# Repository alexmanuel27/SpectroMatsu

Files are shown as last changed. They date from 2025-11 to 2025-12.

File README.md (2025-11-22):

# SpectroMatsu

A lightweight, portable, open-source spectrophotometer designed for in-situ water quality and other compound analysis. Built with the Hamamatsu C12880MA miniature spectrometer sensor and the 3-channel ultraviolet AS7331 light sensor.

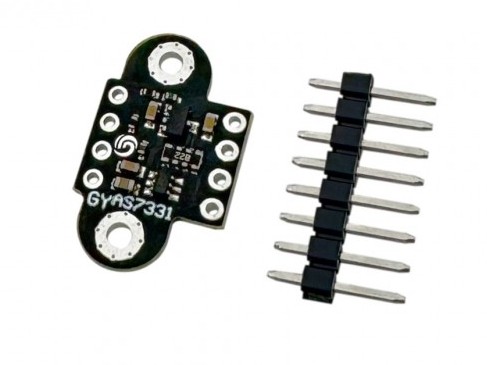
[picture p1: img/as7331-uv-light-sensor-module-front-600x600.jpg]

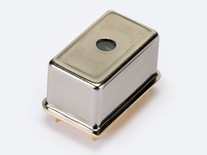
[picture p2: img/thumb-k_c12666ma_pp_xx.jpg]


## Table of Contents

- [Features](#features)
- [Hardware](#hardware)
  - [Sensor](#sensor)
  - [Microcontroller & Display](#microcontroller--display)
  - [Hardware Design (PCB)](#hardware-design-pcb)
- [Software](#software)
- [Installation](#installation)
- [Usage](#usage)
- [License](#license)

## Features

*   **Portable & Low-Cost:** Designed for field use with a focus on affordability.
*   **Open Source:** Hardware schematics and software are freely available.
*   **Real-Time Data:** Captures and displays absorbance spectra.
*   **Local Data Storage:** Saves measurement samples to an external EEPROM.
*   **WiFi Connectivity:** Enables a local web interface for data access and control.
*   **Intuitive Touch Interface:** Easy-to-use graphical menu system on a 1.9" color display.
*   **Sample Management:** Functions to take, save, list, and download sample data (individually or in bulk) via the local web interface.

## Hardware

### Sensor

*   **Model:** 
    *   Hamamatsu C12666MA
    *   AS7331
*   **Type:** Combined miniature linear image sensor for spectral analysis and optical filters with the AS7331 sensor to achieve a broader spectral range.
*   **Spectral Range:** A combination of visible and ultraviolet light, suitable for detecting various water quality indicators through absorbance measurements.
*   **Integration:** Interfaces directly with the custom-designed PCB for signal conditioning and data acquisition.

### Microcontroller & Display

*   **Microcontroller:** ESP32-S3 (specifically, the LilyGo T-Display-S3 module).
*   **Features:** WiFi capability, sufficient processing power for basic spectroscopic calculations.
*   **Display:** 1.9" 320x170 pixel color TFT LCD with capacitive touch panel.
*   **Purpose:** Provides the user interface for control, data visualization (spectra), and menu navigation.

### Hardware Design (PCB)

*   **Status:** Custom-designed PCB specifically for integrating the Hamamatsu C12666MA sensor with the LilyGo T-Display-S3.

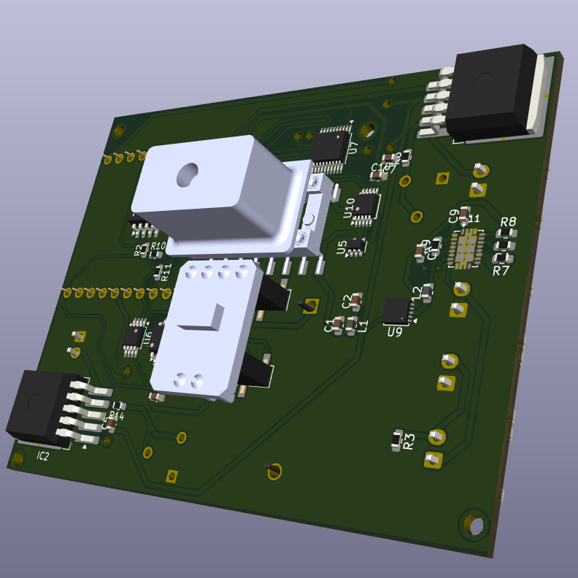
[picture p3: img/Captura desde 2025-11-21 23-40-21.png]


*   **Functionality:**
    *   Includes the necessary components for sensor biasing, timing, and signal conditioning (e.g., amplification, filtering).
    *   Interfaces with the LilyGo T-Display-S3's GPIO pins for data acquisition and control.
    *   Provides stable mechanical mounting for the sensor relative to the optical path.

## Software

*   **Platform:** PlatformIO.
*   **Core Functionality:**
    *   Processes raw sensor data to generate absorbance spectra.
    *   Provides a graphical user interface (GUI) on the TFT display using a state machine architecture.
    *   Handles touch input for navigation and control.
    *   Stores measurement data (samples) on an external EEPROM of the ESP32.
    *   Manages WiFi access point (AP) mode.
    *   Runs a local web server providing a web interface for sample listing and downloading (CSV format).
    *   Implements a simple menu system accessible via the touchscreen.

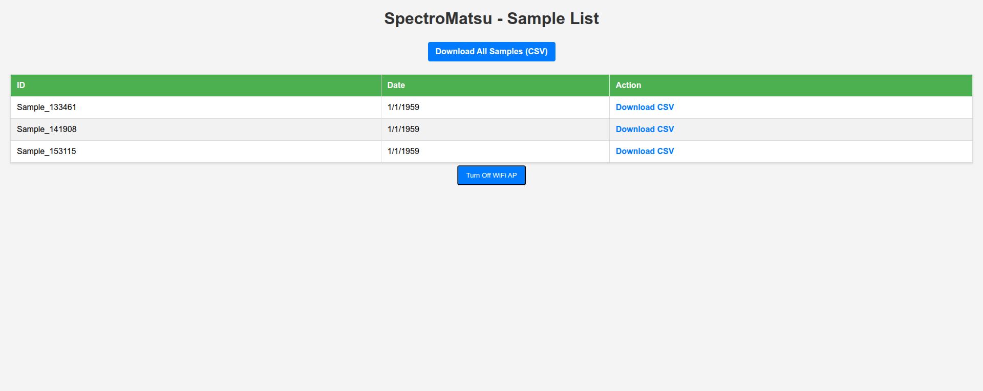
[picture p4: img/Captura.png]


### Key Functionalities

#### Sample Taking:

*   Navigate to the main screen.
*   Press the "REFER" button.
    *   The system saves the blank/reference value for later absorbance calculation.
*   Press the "SAMPLE" button.
    *   The system enters an acquisition and absorbance calculation phase.
*   After acquisition, the resulting spectrum is displayed.
*   Press the "SAVE" button to store the spectrum in the EEPROM with a generated name.

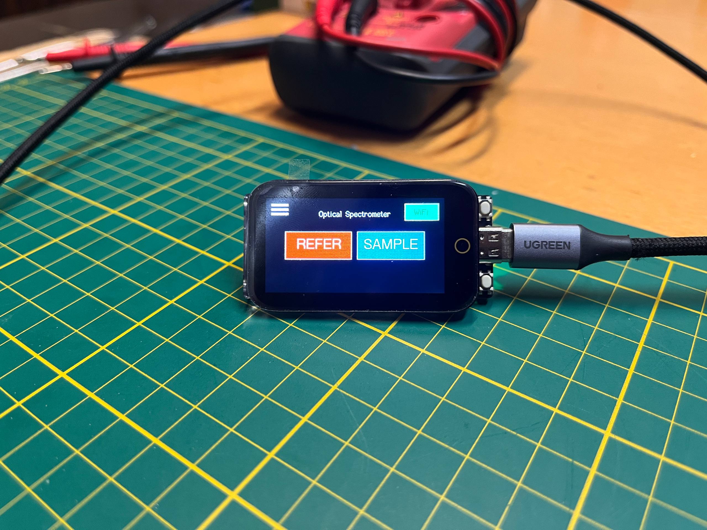
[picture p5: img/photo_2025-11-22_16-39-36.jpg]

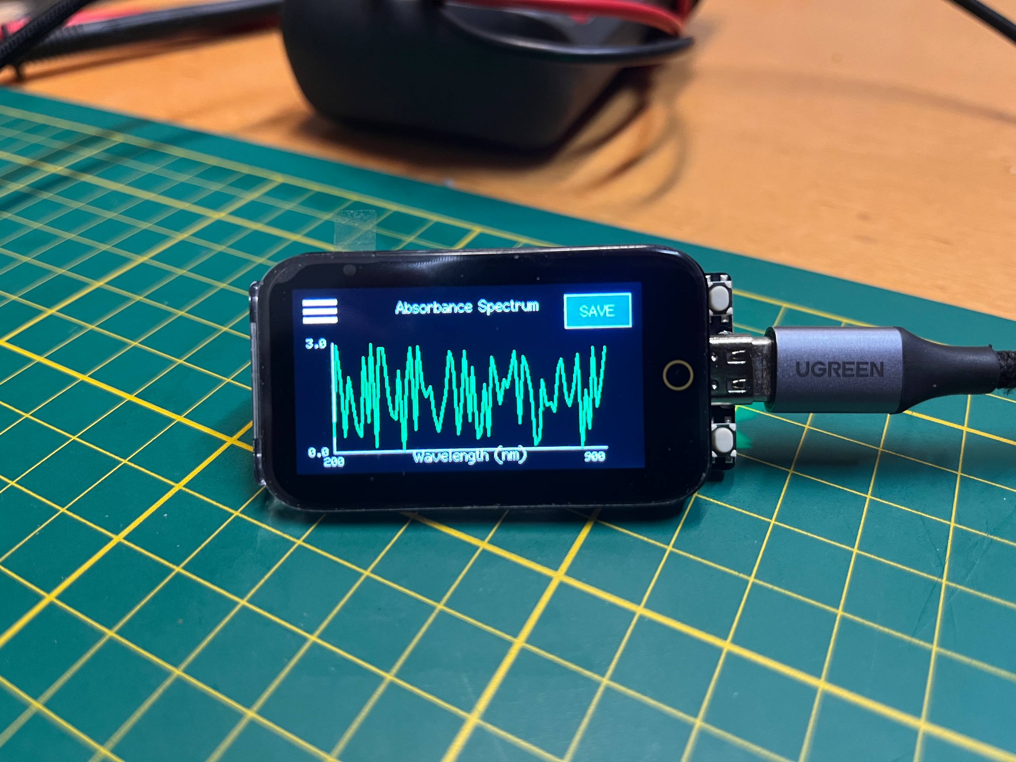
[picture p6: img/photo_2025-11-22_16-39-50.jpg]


#### Sample Listing:

*   Access the main menu (hamburger icon).
*   Select "SAMPLES".
*   A list of saved sample names and dates (default date shown) is displayed on the screen.

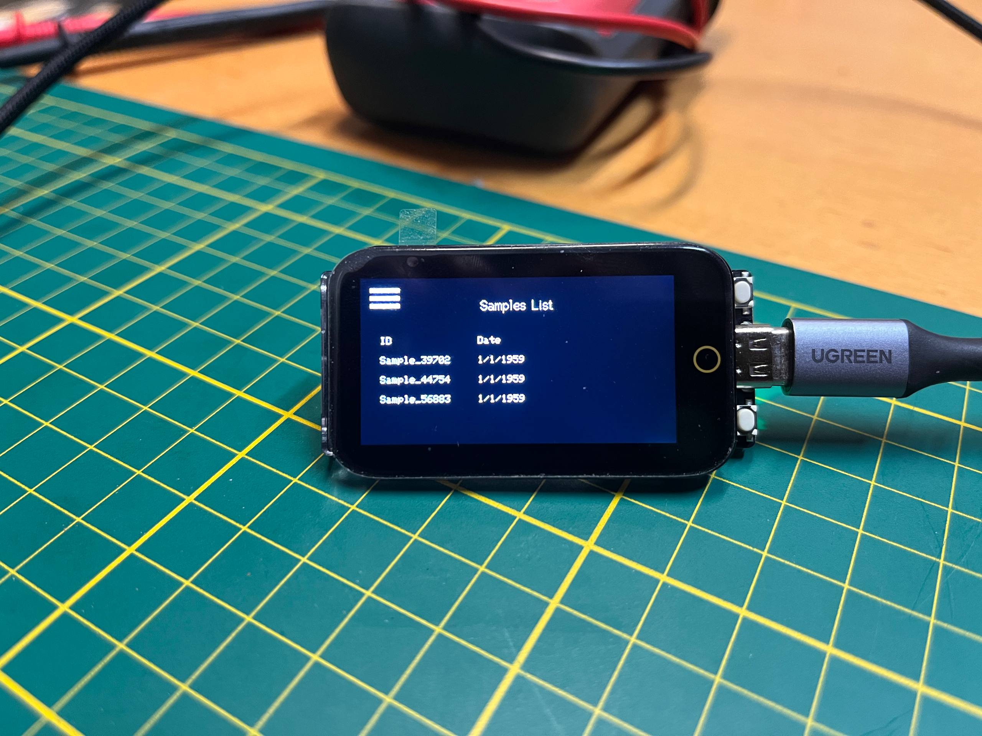
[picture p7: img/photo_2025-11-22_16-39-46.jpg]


#### Local Web Interface:

*   Activate the WiFi AP by pressing the WiFi button on the main screen.
*   Connect your mobile device or computer to the `SpectroMatsu` WiFi network.
*   Open a web browser and navigate to the AP's IP address (typically `192.168.4.1`).
*   View the list of saved samples.
*   Download individual sample data as CSV files.
*   Download all stored samples as a single CSV file.
*   Turn off the WiFi AP from the web interface.

#### Settings & Info:

*   Access system information (firmware version, device model, WiFi status, sample count) via the "SETTINGS" menu.
*   Use the "ABOUT" menu to view a QR code linking to this repository.

## Installation

1.  Clone or download this repository.
2.  Install [PlatformIO](https://platformio.org/) in your preferred IDE (VSCode recommended).
3.  Open the project folder in PlatformIO.
4.  Ensure your LilyGo T-Display-S3 is connected to your computer via USB.
5.  Build and upload the firmware using PlatformIO's upload command (`Ctrl+Alt+U` in VSCode).

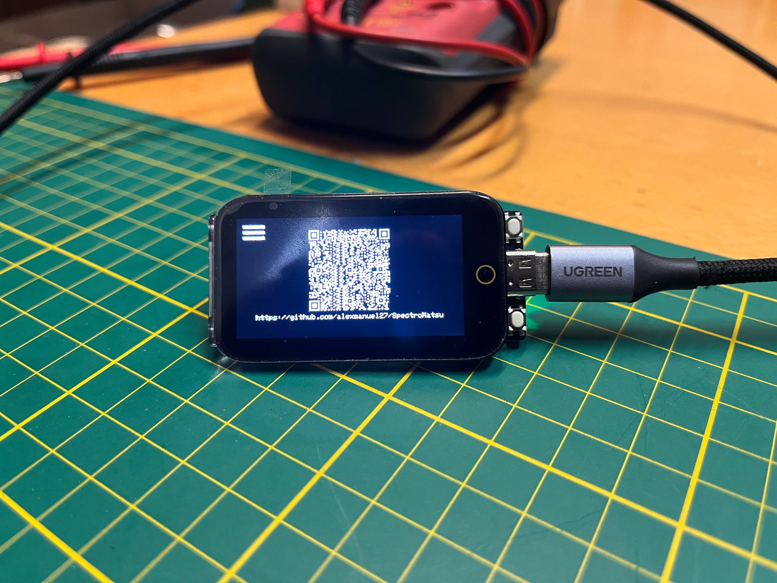
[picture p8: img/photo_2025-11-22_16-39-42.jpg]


## Usage

1.  Power on the device.
2.  Use the touch screen to navigate menus and take samples.
3.  Activate WiFi via the main screen button to access the web interface.
4.  Connect to the `SpectroMatsu` WiFi network and use a web browser to manage samples.

## License

This project is licensed under the MIT License.

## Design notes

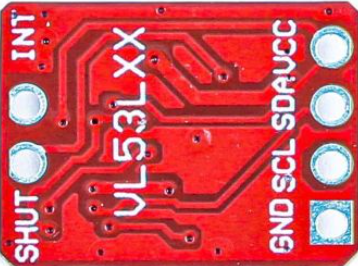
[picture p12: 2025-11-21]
Hardware/3D Comp/vl53l1x-3.snapshot.11/vl531xx/vl53l1x/screenshot 2025-07-30 113826.png

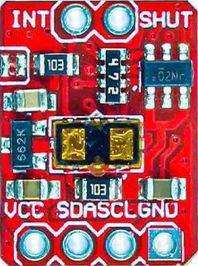
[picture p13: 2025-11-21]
Hardware/3D Comp/vl53l1x-3.snapshot.11/vl531xx/vl53l1x/screenshot 2025-07-25 130046.png

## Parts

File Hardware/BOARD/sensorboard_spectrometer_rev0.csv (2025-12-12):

Reference | Qty | Value | Datasheet | MP | Supplier
R5,R13 | 2 | 5.0K | https://www.bourns.com/docs/Product-Datasheets/3386.pdf | 3386F-1-502TLF | farnell
U10 | 1 | ADS1115IDGS | http://www.ti.com/lit/ds/symlink/ads1113.pdf | ADS1115BQDGSRQ1 | farnell
C1,C2 | 2 | 0.0220uF | https://www.yageogroup.com/content/datasheet/asset/file/KEM_C1002_X7R_SMD | C0603C104K3RACTU | farnell
C3,C4,C5,C7,C8,C9,C10 | 7 | 0.10uF | https://www.yageogroup.com/content/datasheet/asset/file/KEM_C1002_X7R_SMD | C0603C104K3RACTU | farnell
IC1,IC2 | 2 | CAT4101 | https://www.alldatasheet.es/datasheet-pdf/pdf/352063/ONSEMI/CAT4101.html | CAT4104V-GT3 | farnell
U8 | 1 | DS3231MZ | http://datasheets.maximintegrated.com/en/ds/DS3231M.pdf | DS3231MZ+ | farnell
R4 | 1 | 22.10 K | https://www.vishay.com/docs/31010/rcwpm.pdf | ERA3AEB203V | farnell
R10,R11 | 2 | 4.70 K | https://www.vishay.com/docs/31010/rcwpm.pdf | ERJ3EKF4751V | farnell
L2 | 1 | 4.70uH | https://search.murata.co.jp/Ceramy/image/img/P02/JELF243A-0111.pdf | LQW18AS4N7G00D | farnell
L1 | 1 | 100.0uH | https://search.murata.co.jp/Ceramy/image/img/P02/JELF243A-0111.pdf | LQW18ASR10G00D | farnell
U9 | 1 | LT3045xDD | https://www.analog.com/media/en/technical-documentation/data-sheets/LT3045.pdf | LT3045HDD#TRPBF | farnell
R1,R2,R12 | 3 | 10.0 K | https://www.vishay.com/docs/60018/eh.pdf | M55342E12B10B0RT5 | farnell
R3 | 1 | 100.0 K | https://www.vishay.com/docs/31010/rcwpm.pdf | M55342K12B100ERS2 | farnell
R15 | 1 | 0 | https://www.vishay.com/docs/31010/rcwpm.pdf | MCWR06X000 PTL | farnell
R8,R9 | 2 | 40.0 K | https://www.vishay.com/docs/31010/rcwpm.pdf | WR06X3922FTL | farnell
LL1 | 5 | XLamp XHP35.2 | https://www.farnell.com/datasheets/2699640.pdf | XHP35B-00-0000-0D0HD240E | farnell
U6 | 1 | MCP9808_MSOP | http://ww1.microchip.com/downloads/en/DeviceDoc/22203b.pdf | 579-MCP9808-E/MS | mouser
R7 | 1 | 56.20 K | https://www.vishay.com/docs/31010/rcwpm.pdf | ERA3ARB5622V | mouser
R6,R14 | 2 | 500 | https://www.vishay.com/docs/31010/rcwpm.pdf | RC0603FR-07590RL | mouser
U5 | 1 | TLV9001IDCK | https://www.ti.com/lit/ds/symlink/tlv9001.pdf?HQS=dis-dk-null-digikeymode-dsf-pf-null-wwe&ts=1762853433630 | TLV9001IDCKR | mouser
U11 | 1 | TPS61088RHLT | https://www.ti.com/lit/ds/symlink/tps61088.pdf?HQS=dis-dk-null-digikeymode-dsf-pf-null-wwe&ts=1762891137847 | TPS61088RHLT | mouser
U7 | 1 | TRANSLATOR-TXS0108E | https://www.ti.com/lit/ds/symlink/txs0108e.pdf?ts=1763832768609 | TXS0108EPWR | mouser
U4 | 1 | W25Q16JVSS | https://www.winbond.com/resource-files/w25q16jv%20spi%20revg%2003222018%20plus.pdf | W25Q16JVSSIQ | mouser
BAT_IN1,BAT_OU_LILYGO1,SWITCH_SPDT1 | 3 | M02-JST-2MM-SMT | https://www.jst.fr/doc/jst/pdf/jst-connector-catalogue-vol-120e.pdf | 561 | tinytronics
D1,D2 | 2 | LED | https://www.jst.fr/doc/jst/pdf/jst-connector-catalogue-vol-120e.pdf | 561 | tinytronics
BT1 | 1 | Battery_Cell | https://www.mouser.be/datasheet/3/201/1/1058.PDF | 1203 | tinytronics
U3 | 1 | LILTGO touch | https://github.com/Xinyuan-LilyGO/T-Display-S3 | 4807 | tinytronics

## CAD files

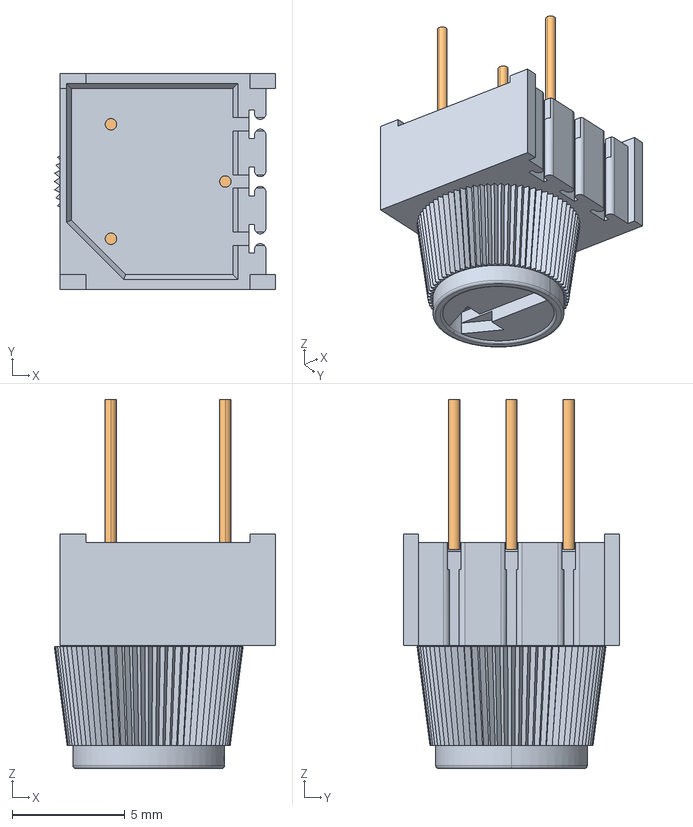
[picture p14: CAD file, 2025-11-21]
Hardware/3D Comp/3386F%28T%29.stp
9.83 x 9.58 x 16.4 mm
MANIFOLD_SOLID_BREP_18751
MANIFOLD_SOLID_BREP_18840
MANIFOLD_SOLID_BREP_18929
MANIFOLD_SOLID_BREP_19018

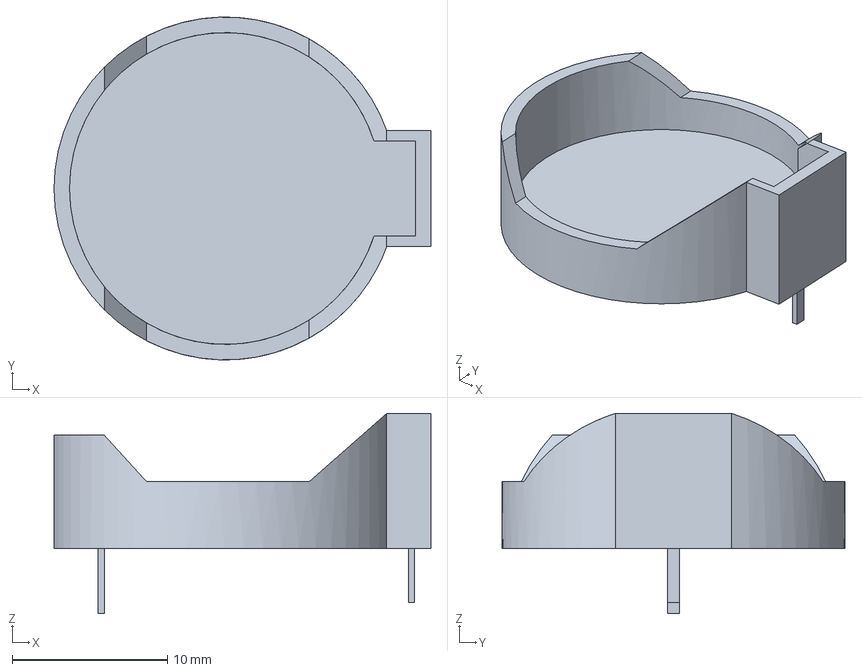
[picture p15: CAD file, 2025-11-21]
Hardware/3D Comp/bh-25f-1-cr2032-battery-holder-1.snapshot.1/BH-25F-1.step
24.3 x 22.1 x 12.9 mm

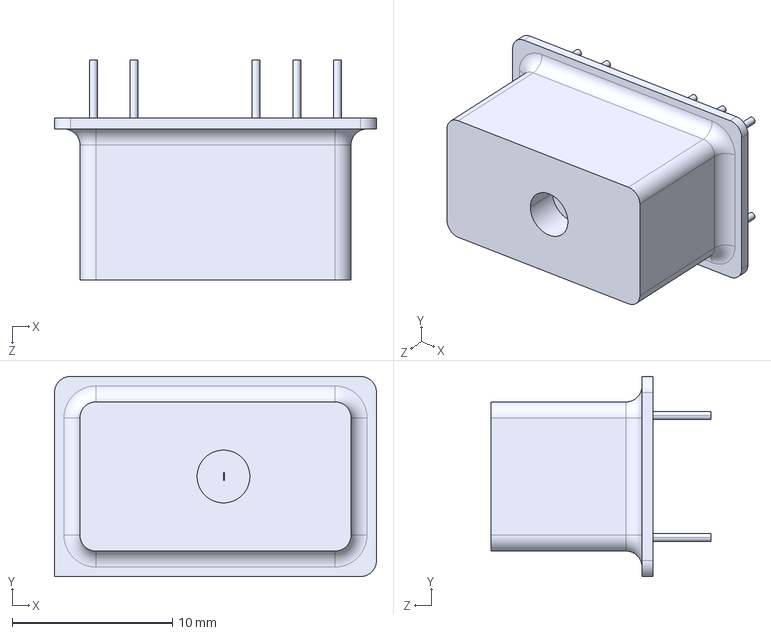
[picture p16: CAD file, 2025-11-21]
Hardware/3D Comp/User Library-C12880MA-1 (1)/User Library-C12880MA-1.STEP
20.1 x 12.5 x 13.7 mm

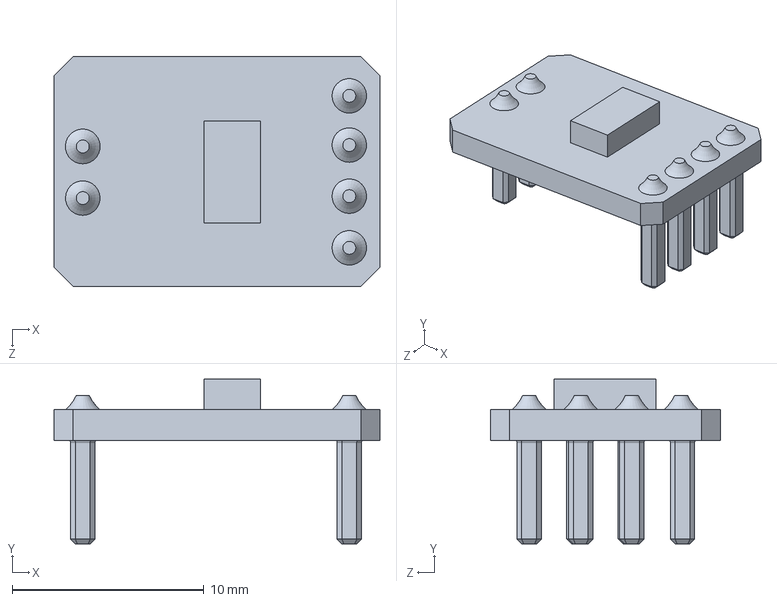
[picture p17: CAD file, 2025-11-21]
Hardware/3D Comp/vl53l1x-3.snapshot.11/vl531xx/vl53l1x/vl531xx.SLDPRT
17.0 x 8.60 x 12.0 mm

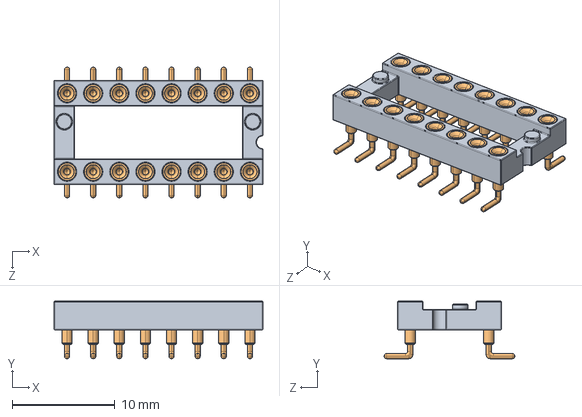
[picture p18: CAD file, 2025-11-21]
Hardware/3D Comp/110-xx-316-41-105000.STEP
20.3 x 5.59 x 12.7 mm
110-xx-316-41-001000
Right-Angle-Pin-SN x 16

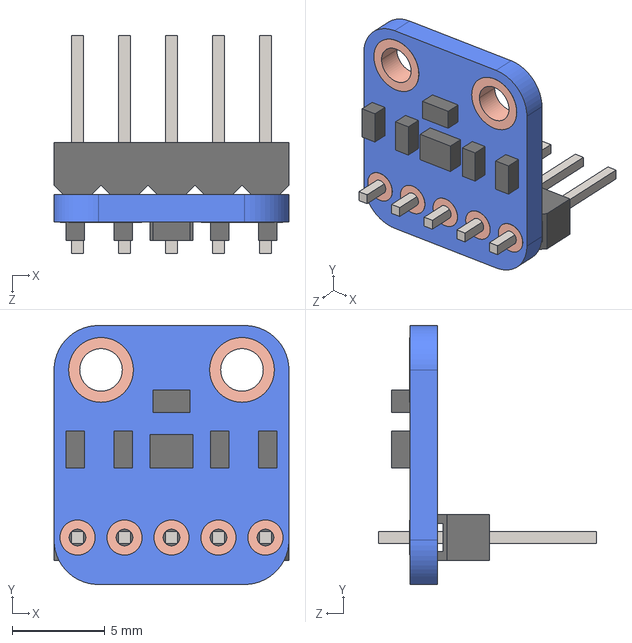
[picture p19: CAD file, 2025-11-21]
Hardware/3D Comp/User Library-VEML6070_UV.STEP
12.7 x 14.0 x 11.8 mm

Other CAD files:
Hardware/3D Comp/vl53l1x-3.snapshot.11/vl531xx/vl53l1x/vl531x.STEP
Hardware/3D Comp/vl53l1x-3.snapshot.11/vl531xx/vl53l1x/vl531x.SLDPRT

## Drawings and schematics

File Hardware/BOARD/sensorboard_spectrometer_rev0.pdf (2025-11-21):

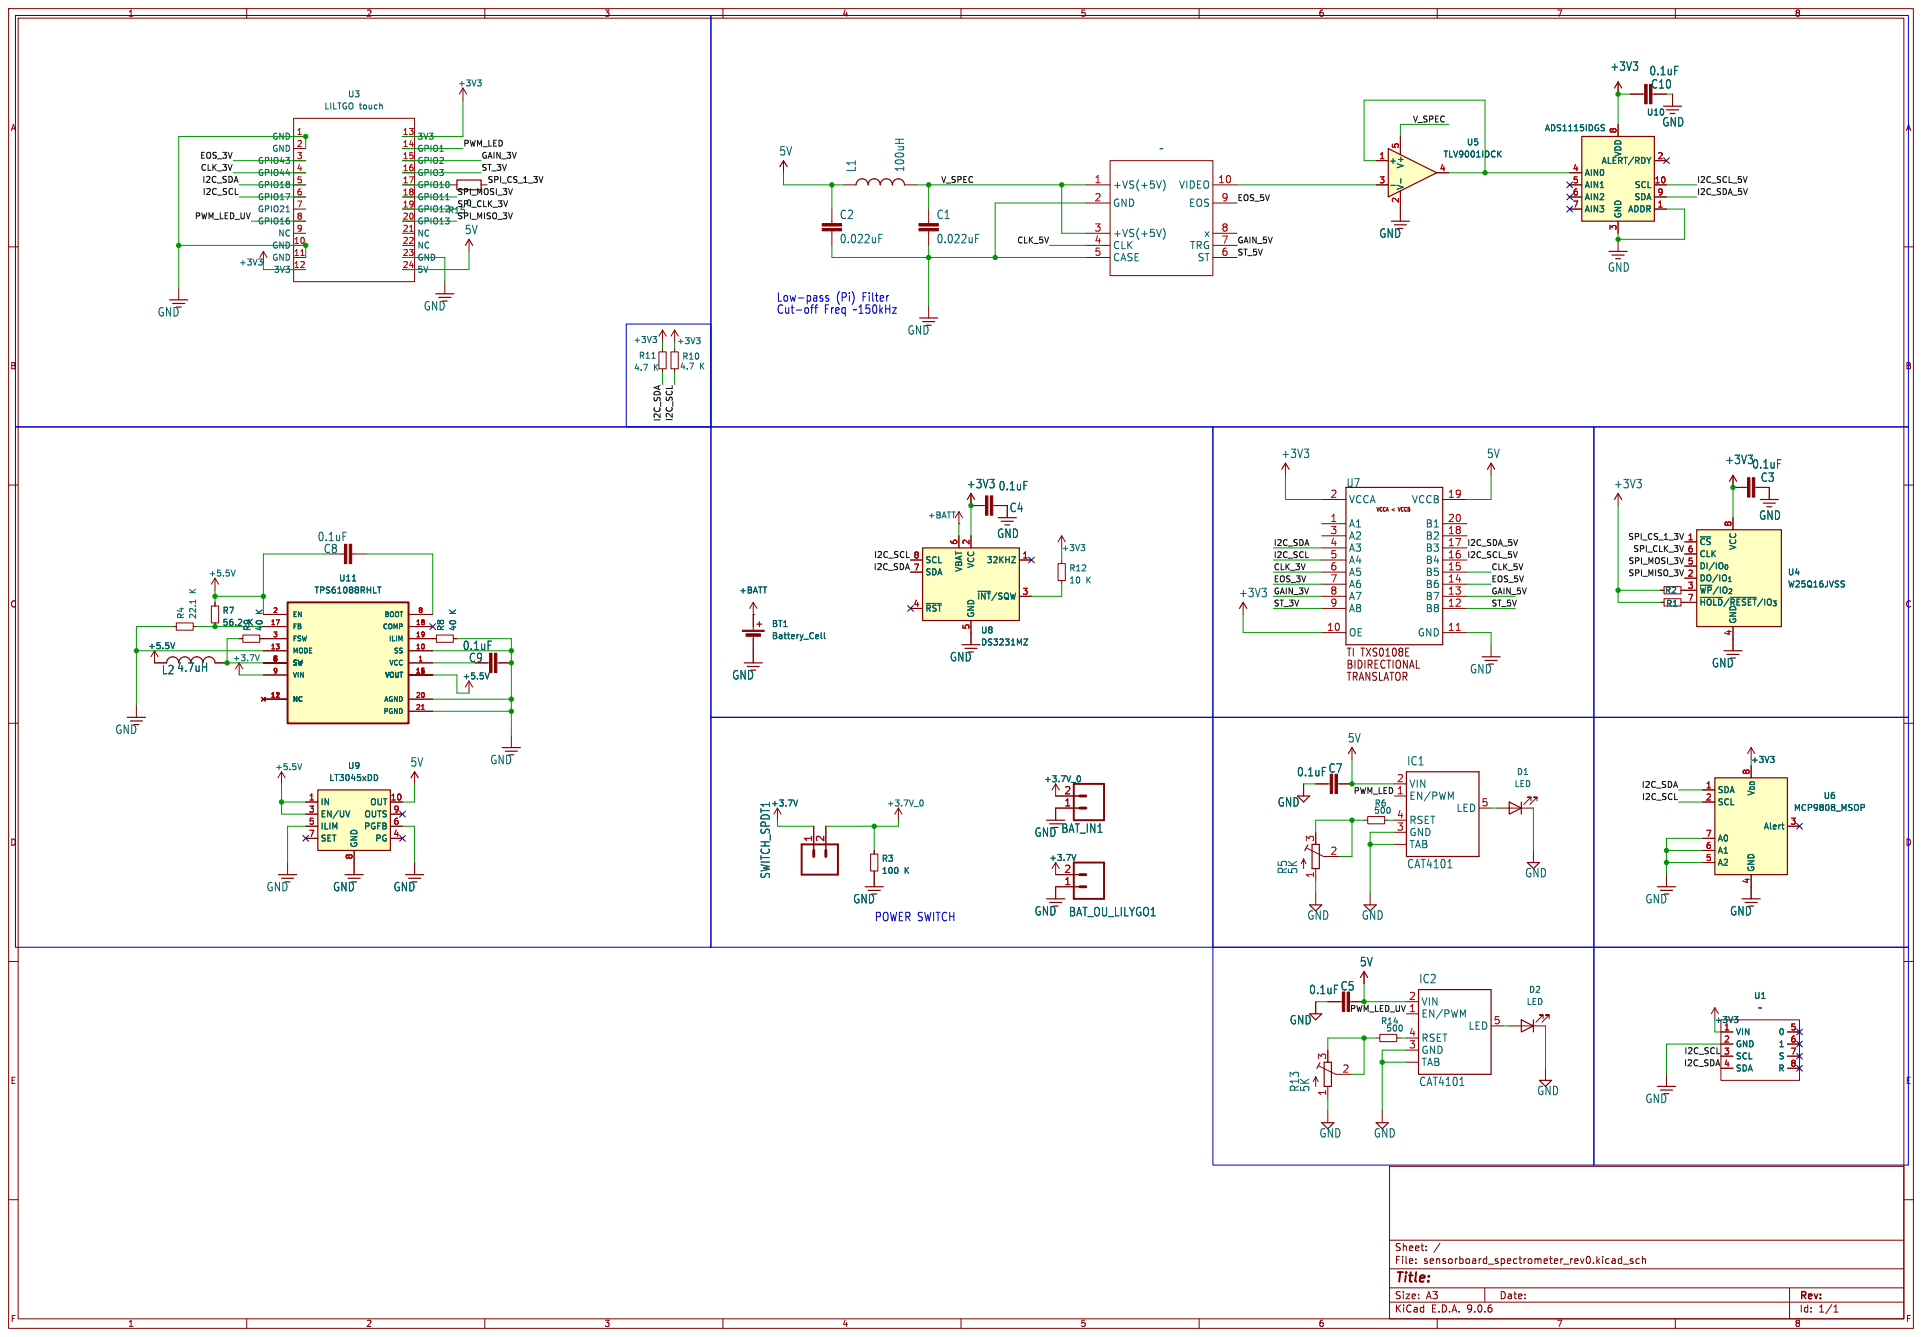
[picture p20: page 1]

GPIO3 16 GND 1 GND 2 GPIO43 3 GPIO44 4 GPIO18 5 GPIO17 6 GPIO21 7 GPIO16 8 NC 9 GND 10 GND 11

8 OUT 10 OUTS 9 PGFB 6 PG 4 C9

8 OUT 10 OUTS 9 PGFB 6 PG 4 U9
LT3045xDD

Id: 1/1 Title: File: sensorboard_spectrometer_rev0.kicad_sch Sheet: /

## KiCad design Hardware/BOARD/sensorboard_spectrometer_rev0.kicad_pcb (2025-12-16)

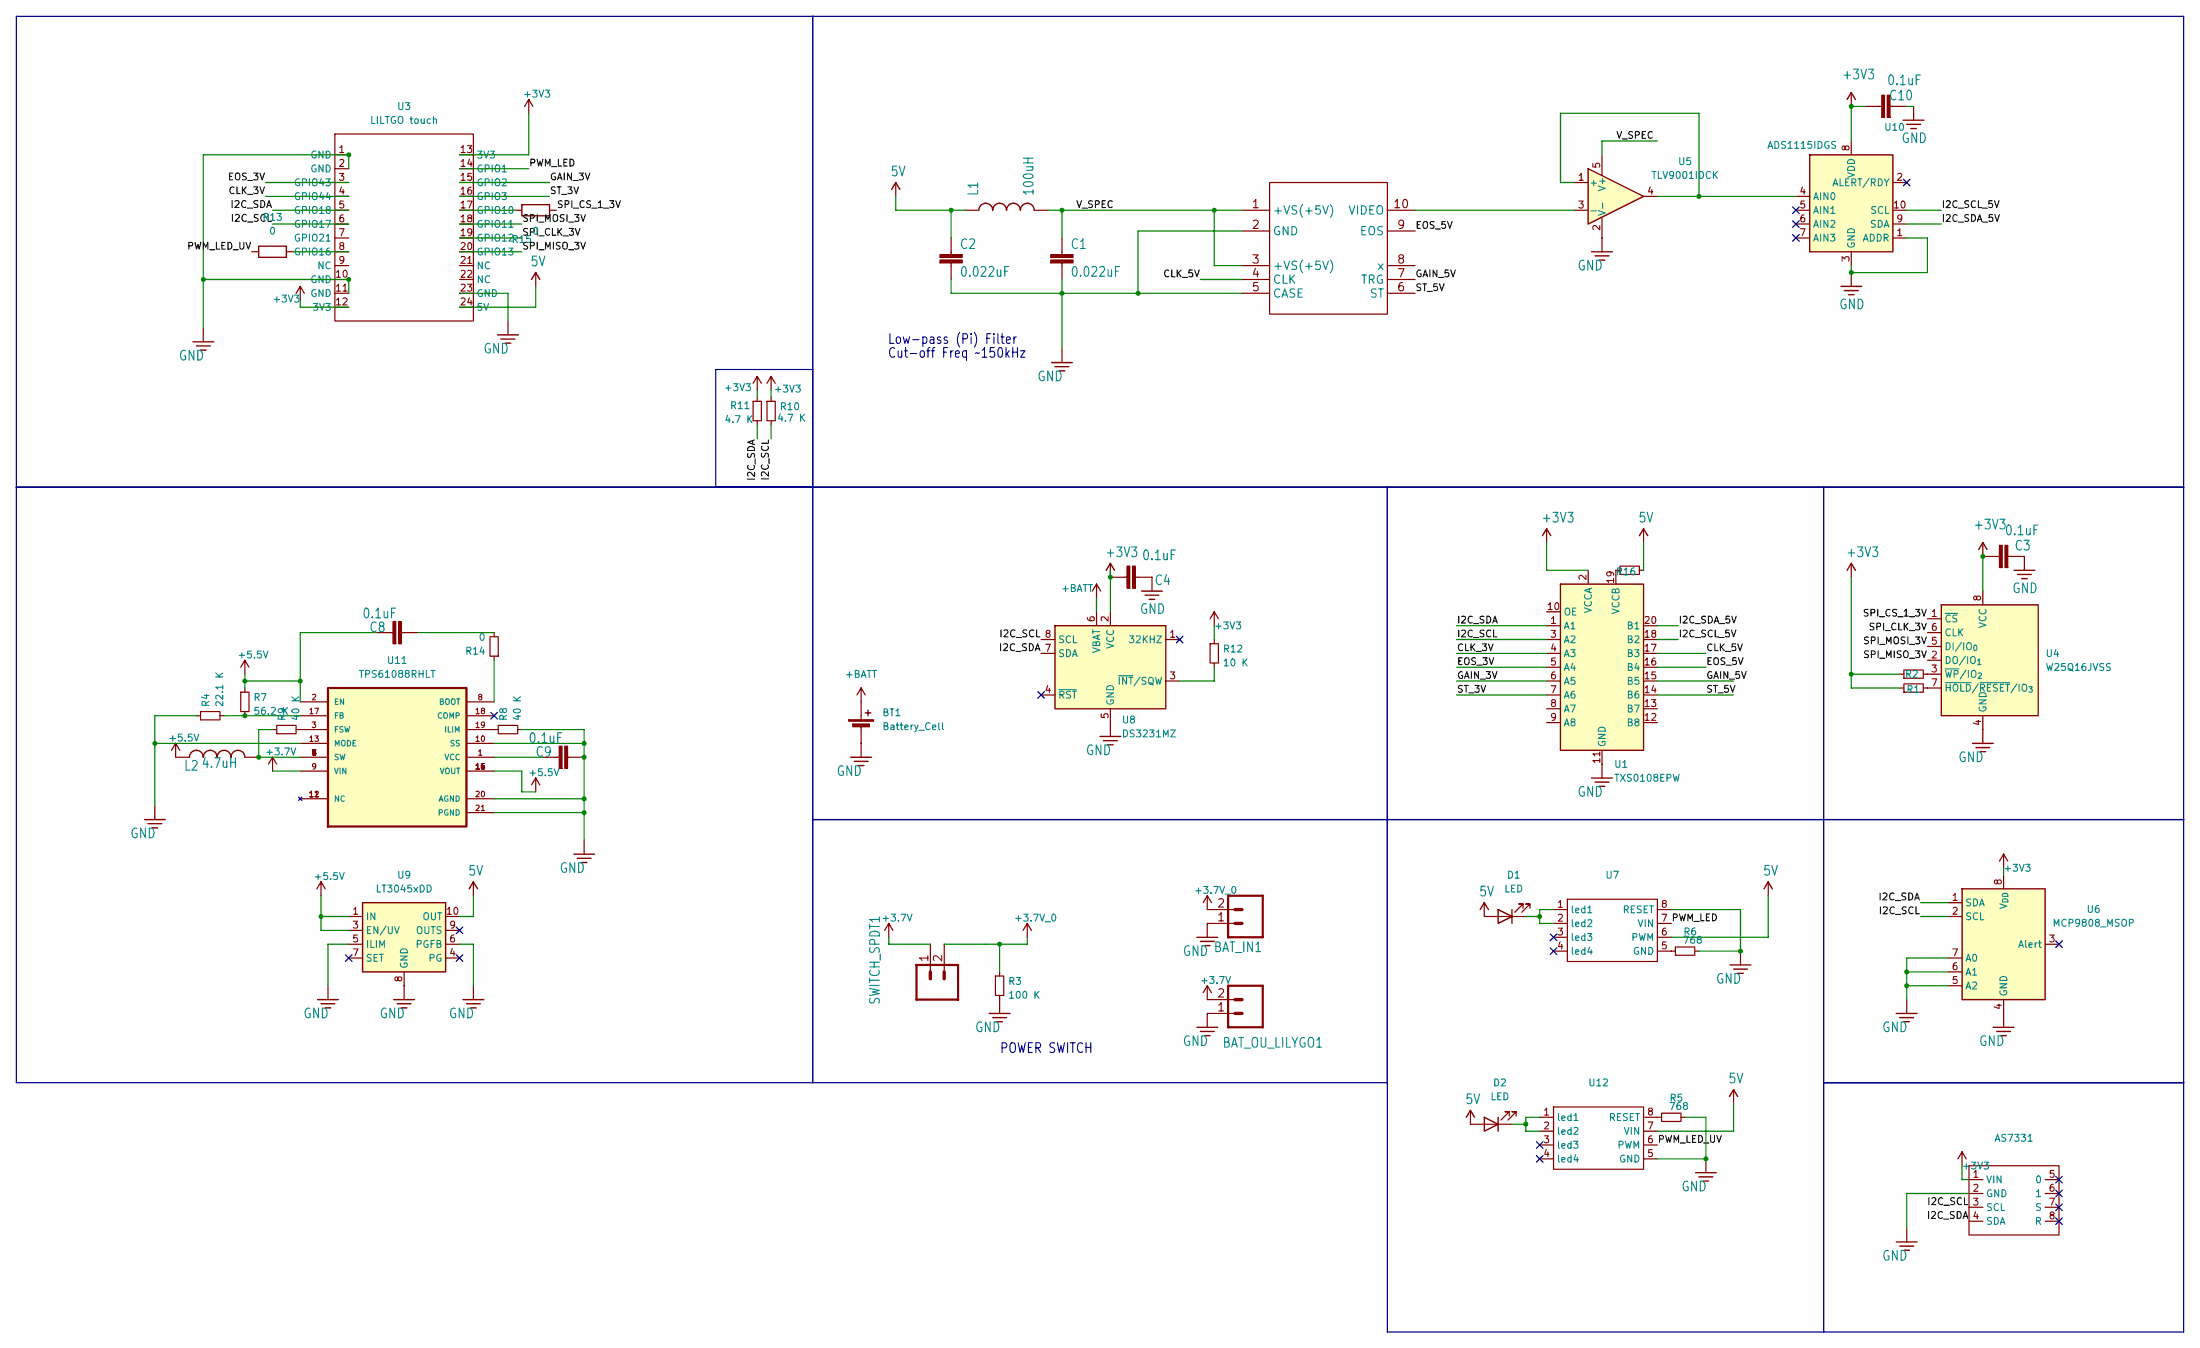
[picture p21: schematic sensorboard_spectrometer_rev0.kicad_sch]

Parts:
AS7331: as7331_SMD
BAT_IN1: M02-JST-2MM-SMT; JST_EH_S2B-EH_1x02_P2.50mm_Horizontal
BAT_OU_LILYGO1: M02-JST-2MM-SMT; JST_EH_S2B-EH_1x02_P2.50mm_Horizontal
BT1: Battery_Cell; BatteryHolder_MYOUNG_BS-07-A1BJ001_CR2032
C1, C2: 0.022uF; C_0603_1608Metric
C3: 0.1uF; C_1206_3216Metric
C4, C8, C9, C10: 0.1uF; C_0603_1608Metric
D1, D2: LED; JST_EH_S2B-EH_1x02_P2.50mm_Horizontal
L1: 100uH; L_0603_1608Metric
L2: 4.7uH; L_0603_1608Metric
R1, R12: 10 K; R_0603_1608Metric; LCSC C25804
R2: 10 K; R_1206_3216Metric; LCSC C25804
R3: 100 K; R_0603_1608Metric; LCSC C25804
R4: 22.1 K; R_0603_1608Metric; LCSC C25804
R5, R6: 768; R_0603_1608Metric; LCSC C25804
R7: 56.2 K; R_0603_1608Metric; LCSC C25804
R8, R9: 40 K; R_0603_1608Metric; LCSC C25804
R10: 4.7 K; R_0603_1608Metric; LCSC C25804
R11: 4.7 K; R_1206_3216Metric; LCSC C25804
R13, R15: 0; R_1206_3216Metric
R14: 0; R_0603_1608Metric; LCSC C25804
R16: 0; R_1206_3216Metric; LCSC C25804
SWITCH_SPDT1: M02-JST-2MM-SMT; JST_EH_S2B-EH_1x02_P2.50mm_Horizontal
U1: TXS0108EPW; TSSOP-20_4.4x6.5mm_P0.65mm
U2: C12880MA_SMD
U3: LILTGO touch; Untitled
U4: W25Q16JVSS; SOIC-8_5.3x5.3mm_P1.27mm
U5: TLV9001IDCK; SOT-353_SC-70-5
U6: MCP9808_MSOP; MSOP-8_3x3mm_P0.65mm
U7, U12: PowerIntegrations_SO-8
U8: DS3231MZ; SOIC-8_3.9x4.9mm_P1.27mm; LCSC C107410
U9: LT3045xDD; DFN-10-1EP_3x3mm_P0.5mm_EP1.65x2.38mm
U10: ADS1115IDGS; TSSOP-10_3x3mm_P0.5mm
U11: TPS61088RHLT; IC_MSP430FR2522IRHLR; PARTREV August 2021

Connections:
5V: C2.1, D1.2 (A), D2.2 (A), L1.1, R16.2, U3.24 (5V), U7.6 (PWM), U9.10 (OUT), U12.7 (VIN)
+3.7V: BAT_OU_LILYGO1.2 (1), SWITCH_SPDT1.1 (2), U11.9 (VIN)
+3.7V_0: BAT_IN1.2 (1), R3.1, SWITCH_SPDT1.2 (1)
+3V3: AS7331.1 (VIN), C3.1, C4.1, C10.1, R1.1, R2.1, R10.1, R11.1, R12.1, U1.2 (VCCA), U3.12 (3V3), U3.13 (3V3), U4.8 (VCC), U6.8 (V_{DD}), U8.2 (VCC), U10.8 (VDD)
+5.5V: C8.1, L2.1, R7.1, U9.1 (IN), U9.2 (IN), U9.3 (EN/UV), U11.2 (EN), U11.14 (VOUT), U11.15 (VOUT), U11.16 (VOUT)
+BATT: BT1.1 (+), U8.6 (VBAT)
/CLK_3V: U1.4 (A3), U3.4 (GPIO44)
/CLK_5V: U1.17 (B3), U2.4 (CLK)
/EOS_3V: U1.5 (A4), U3.3 (GPIO43)
/EOS_5V: U1.16 (B4), U2.9 (EOS)
/GAIN_3V: U1.6 (A5), U3.15 (GPIO2)
/GAIN_5V: U1.15 (B5), U2.7 (TRG)
/I2C_SCL: AS7331.3 (SCL), R10.2, U1.3 (A2), U3.6 (GPIO17), U6.2 (SCL), U8.8 (SCL)
/I2C_SCL_5V: U1.18 (B2), U10.10 (SCL)
/I2C_SDA: AS7331.4 (SDA), R11.2, U1.1 (A1), U3.5 (GPIO18), U6.1 (SDA), U8.7 (SDA)
/I2C_SDA_5V: U1.20 (B1), U10.9 (SDA)
/PWM_LED: U3.14 (GPIO1), U7.7 (VIN)
/PWM_LED_UV: R13.1, U12.6 (PWM)
/SPI_CLK_3V: U3.19 (GPIO12), U4.6 (CLK)
/SPI_CS_1_3V: R15.1, U4.1 (~CS)
/SPI_MISO_3V: U3.20 (GPIO13), U4.2 (DO/IO_{1})
/SPI_MOSI_3V: U3.18 (GPIO11), U4.5 (DI/IO_{0})
/ST_3V: U1.7 (A6), U3.16 (GPIO3)
/ST_5V: U1.14 (B6), U2.6 (ST)
/V_SPEC: C1.1, L1.2, U2.1 (+VS(+5V)), U2.3 (+VS(+5V)), U5.5 (V+)
GND: AS7331.2 (GND), BAT_IN1.1 (2), BAT_OU_LILYGO1.1 (2), BT1.2 (-), C1.2, C2.2, C3.2, C4.2, C9.2, C10.2, R3.2, R4.1, R5.2, R6.2, R8.2, U1.11 (GND), U2.2 (GND), U2.5 (CASE), U3.1 (GND), U3.2 (GND), U3.10 (GND), U3.11 (GND), U3.23 (GND), U4.4 (GND), U5.2 (V-), U6.4 (GND), U6.5 (A2), U6.6 (A1), U6.7 (A0), U7.8 (RESET), U8.5 (GND), U9.5 (ILIM), U9.6 (PGFB), U9.8 (GND), U9.11 (GND), U10.1 (ADDR), U10.3 (GND), U11.10 (SS), U11.13 (MODE), U11.20 (AGND), U11.21 (PGND), U12.5 (GND)
unnamed: C8.2, R14.2
unnamed: D1.1 (K), U7.1 (led1), U7.2 (led2)
unnamed: D2.1 (K), U12.1 (led1), U12.2 (led2)
unnamed: L2.2, R9.1, U11.4 (SW), U11.5 (SW), U11.6 (SW), U11.7 (SW)
unnamed: R16.1, U1.19 (VCCB)
unnamed: U2.10 (VIDEO), U5.3 (-)
unnamed: R15.2, U3.17 (GPIO10)
unnamed: R13.2, U3.8 (GPIO16)
unnamed: R1.2, U4.7 (~HOLD/~RESET/IO_{3})
unnamed: R2.2, U4.3 (~WP/IO_{2})
unnamed: R6.1, U7.5 (GND)
unnamed: R12.2, U8.3 (~INT/SQW)
unnamed: U5.1 (+), U5.4, U10.4 (AIN0)
unnamed: R14.1, U11.8 (BOOT)
unnamed: R4.2, R7.2, U11.17 (FB)
unnamed: R9.2, U11.3 (FSW)
unnamed: R8.1, U11.19 (ILIM)
unnamed: C9.1, U11.1 (VCC)
unnamed: R5.1, U12.8 (RESET)

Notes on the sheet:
Low-pass (Pi) Filter
POWER SWITCH
Cut-off Freq ~150kHz

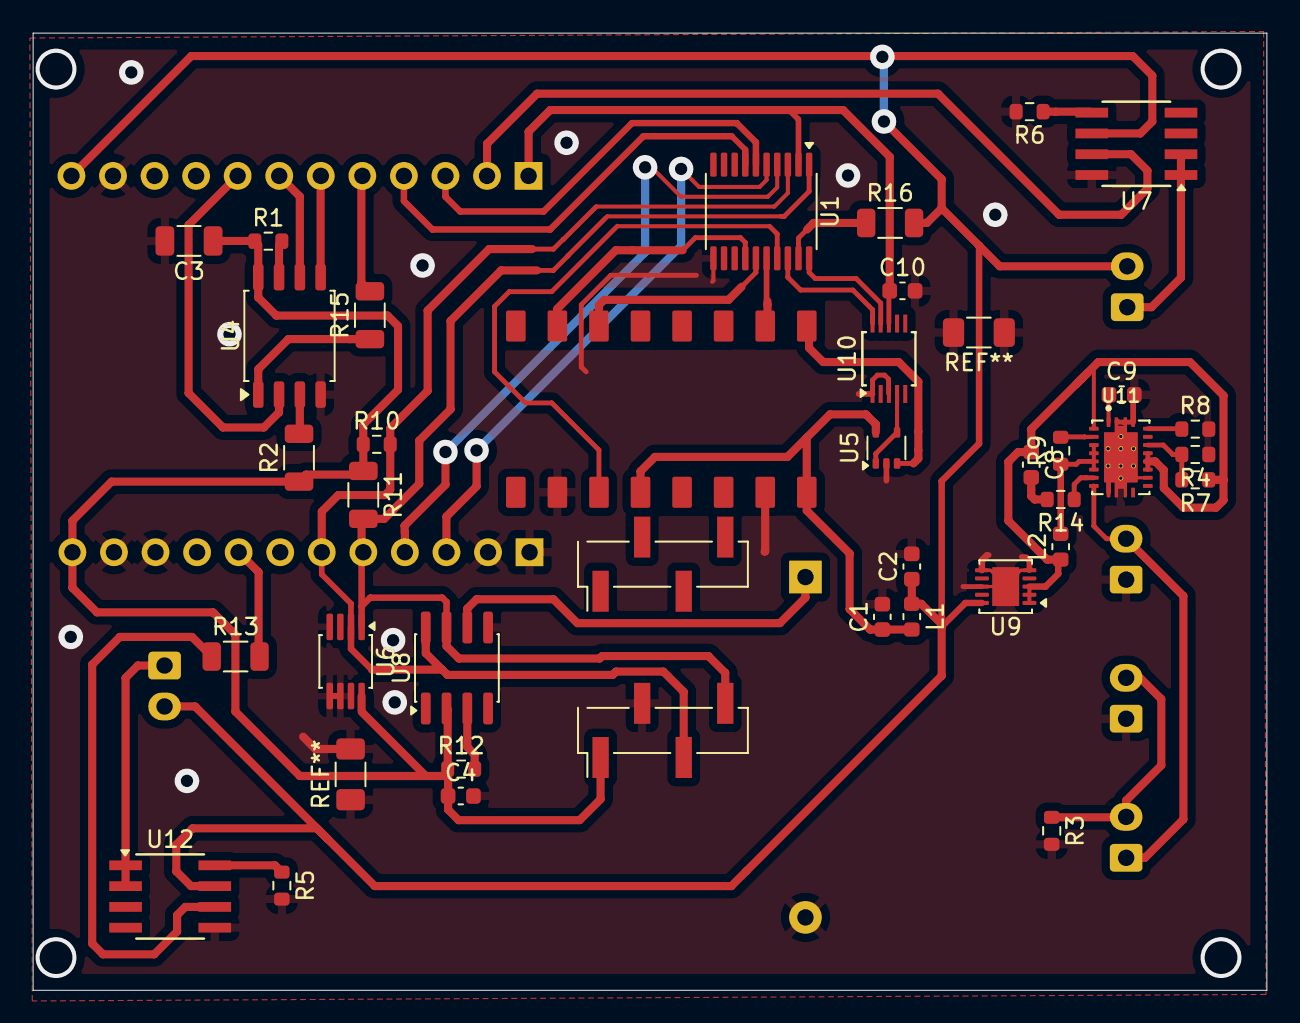
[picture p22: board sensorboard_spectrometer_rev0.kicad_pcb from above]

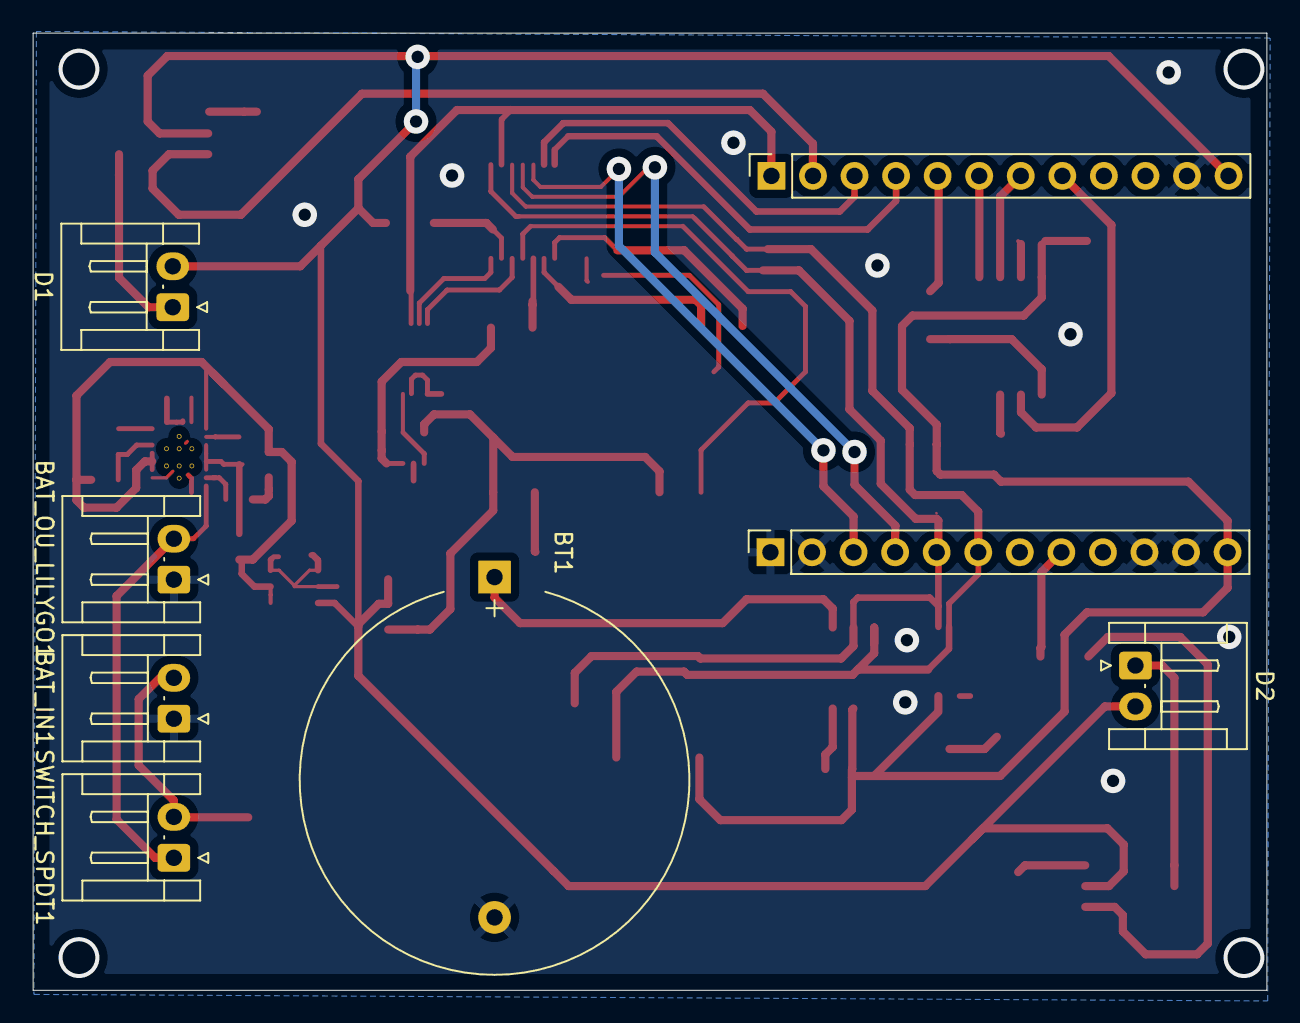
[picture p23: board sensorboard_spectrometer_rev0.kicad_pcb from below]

Board: 2 copper layers, 75.4 x 58.5 mm, 44 parts (7 on the bottom side), 45 nets.

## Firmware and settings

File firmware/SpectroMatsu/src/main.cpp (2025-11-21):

// src/main.cpp
#include <Arduino.h>
#include <TFT_eSPI.h>
#include <TouchDrvCSTXXX.hpp>
#include "ui/ScreenManager.h"
#include "touch/TouchHandler.h"

// Instancias globales (necesarias para que los módulos puedan acceder a ellas)
TFT_eSPI tft = TFT_eSPI();
TouchDrvCSTXXX touch = TouchDrvCSTXXX();

ScreenManager screenManager;
TouchHandler touchHandler(&screenManager);

void setup() {
    Serial.begin(115200);
    // No iniciamos WiFi aquí si solo usamos AP y lo manejamos internamente en ScreenManager
    // WiFi.begin(); // Comentado
    screenManager.init();
    touchHandler.init();
    Serial.println("System initialized.");
}

void loop() {
    touchHandler.handleTouch();
    screenManager.update();
}

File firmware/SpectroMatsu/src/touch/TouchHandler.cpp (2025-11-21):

// src/touch/TouchHandler.cpp
#include "TouchHandler.h"
#include <TouchDrvCSTXXX.hpp>
#include <TFT_eSPI.h>
extern TFT_eSPI tft; // Global display instance
extern TouchDrvCSTXXX touch; // Global touch sensor instance

TouchHandler::TouchHandler(ScreenManager* sm) : _screenManager(sm) {}

void TouchHandler::init() {
    touch.setPins(BOARD_TOUCH_RST, BOARD_TOUCH_IRQ);
    if (!touch.begin(Wire, CST328_SLAVE_ADDRESS, BOARD_I2C_SDA, BOARD_I2C_SCL)) {
        Serial.println("Failed init CST328 Device!");
        if (!touch.begin(Wire, CST816_SLAVE_ADDRESS, BOARD_I2C_SDA, BOARD_I2C_SCL)) {
            Serial.println("Failed init CST816 Device!");
            while (1) {
                Serial.println("Not find touch device!");
                delay(1000);
            }
        }
    }
    touch.disableAutoSleep();
}

void TouchHandler::handleTouch() {
    uint8_t touched = touch.getPoint(_x, _y, touch.getSupportTouchPoint());
    if (touched) {
        for (int i = 0; i < touched; ++i) {
            Serial.print("Touch Raw X["); Serial.print(i); Serial.print("]:"); Serial.print(_x[i]);
            Serial.print(" Y["); Serial.print(i); Serial.print("]:"); Serial.print(_y[i]); Serial.println();

            int mappedX, mappedY;
            transformTouchCoords(_x[i], _y[i], mappedX, mappedY);

            Serial.print("Mapped Touch X:"); Serial.print(mappedX); Serial.print(" Y:"); Serial.println(mappedY);

            _screenManager->processTouch(mappedX, mappedY); // Forward to ScreenManager
        }
    }
    delay(5);
}

void TouchHandler::transformTouchCoords(int16_t rawX, int16_t rawY, int& mappedX, int& mappedY) {
    int touch_width = 320;   // Touch panel native width
    int touch_height = 170;  // Touch panel native height
    int tft_width = tft.width();  // Display width (170)
    int tft_height = tft.height(); // Display height (320)

    // Normalize raw touch to display size
    int adjusted_x = map(rawX, 0, touch_width, 0, tft_width);
    int adjusted_y = map(rawY, 0, touch_height, 0, tft_height);

    // Apply rotation transformation: Touch (0) → Display (1)
    // X_display = Y_touch
    // Y_display = Height - 1 - X_touch
    mappedX = adjusted_y;
    mappedY = tft_height - 1 - adjusted_x;
}

bool TouchHandler::isPointInRect(int16_t px, int16_t py, int16_t rx, int16_t ry, int16_t rw, int16_t rh) {
    return (px >= rx && px <= rx + rw && py >= ry && py <= ry + rh);
}

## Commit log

2025-11-04 I created the hardware and placed the first components
    [sensorboard_spectrometer_rev0.kicad_sch]
2025-11-07 Add Lilygo and the rest of the components
    [sensorboard_spectrometer_rev0.kicad_sch]
2025-11-21 new pcb with the as7331(uv sensor)
    [110-xx-316-41-105000.STEP, 3386F%28T%29.stp, BH-25F-1.step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]
2025-12-12 before maked
    [sensorboard_spectrometer_rev0.csv, sensorboard_spectrometer_rev0.kicad_pcb, sensorboard_spectrometer_rev0.kicad_sch]
2025-12-12 alex suggest changes
    [sensorboard_spectrometer_rev0.kicad_pcb, sensorboard_spectrometer_rev0.kicad_sch]
2025-12-13 not shot resistors
    [sensorboard_spectrometer_rev0.kicad_pcb]
2025-12-16 alex suggest changes again...
    [sensorboard_spectrometer_rev0.kicad_pcb]
